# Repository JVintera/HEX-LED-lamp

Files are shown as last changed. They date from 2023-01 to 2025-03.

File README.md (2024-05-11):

# HEX-LED-lamp
<h1>LED lampička na tři způsoby</h1>
 
<h2>LED lampička</h2>
<p>Původní verze využívá LED modul ze žárovky. Následně vytvořena varianta se supersvítivými LED, aby bylo možné použít lampičku i jako dětskou promítačku.</p>
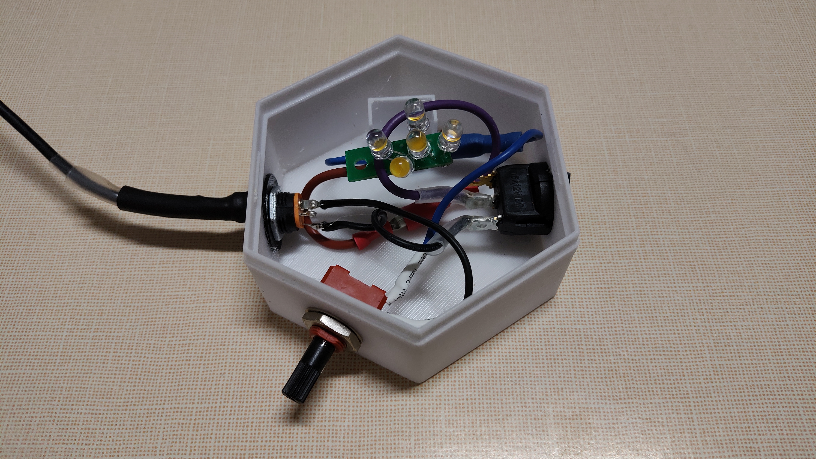
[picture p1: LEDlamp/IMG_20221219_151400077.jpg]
Lampička s LED modulem ze žárovky

LED lampička

<h3>Schéma zapojení</h3>
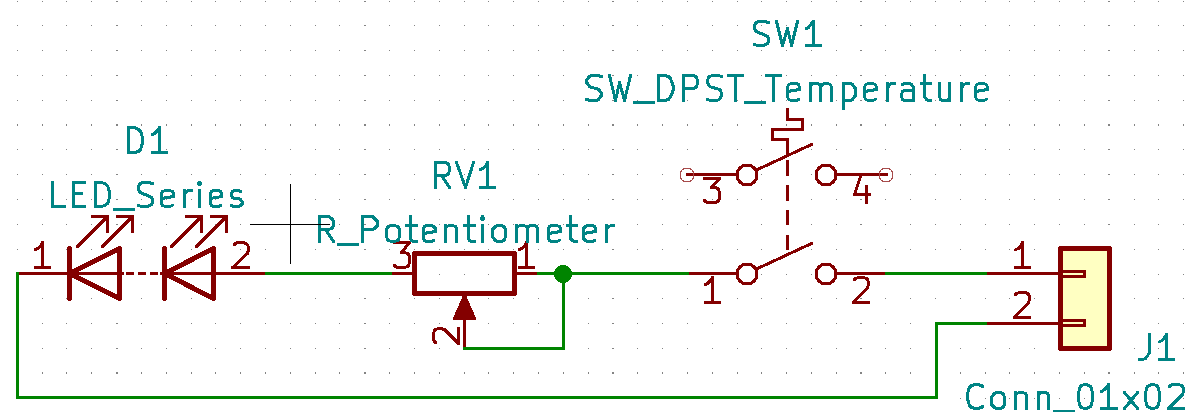
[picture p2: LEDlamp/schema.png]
Chema zapojeni


<h3>Soupis použitých komponent</h3>
<ul>
  <li>SW1 - spínač - <a href="https://ecom.cz/eshop/detail/56333-VP-R13-112B-BRBT2">VP-R13-112B BRBT2</a></li>
  <li>RV1 - trimr - <a href="https://ecom.cz/eshop/detail/48315-MCA14-NHC0-10K-KA">MCA14 NHC0 10K KA</a></li>
  <li>Hřídelka k trimru - <a href="https://ecom.cz/eshop/detail/3047-HRIDEL-CA-14073-1">HRIDEL CA-14073-1</a></li>
  <li>J1 - napájecí konektor - <a href="https://www.laskakit.cz/napajeci-konektor-dc-022-5-5-2-1mm-do-panelu/">Napájecí konektor DC-022 5,5/2,1mm - do panelu</a></li>
  <li>D1 - LED - podle potřeby: LED modul ze žárovky, nebo např. <a href="https://ecom.cz/eshop/detail/29727-LED-FYL-5014UWC1C">LED-FYL-5014UWC1C</a></li>
  <li>Zdroj - podle použitých LED, často je možné použít nabíječku na telefon</li>
</ul>

<h3>3D modely tištěných dílů a fotografie</h3>
<p>Model krabičky vychází z <a href="https://www.thingiverse.com/thing:2503641">Hexagonal LED Lamp with USB chargeable 18650 battery</a></p>
<p>3D modely pro tisk <a href="https://www.printables.com/cs/model/289219-hexagon-led-lamp">Hexagon LED lamp</a></p>

<h3>Problémy a řešení</h3>
<p>Robírání LED žárovek: Žárovka ve které odešel zdroj může mít skleněnou, nebo plastovou baňku. U skleněné lze nahřát lepidlo v místě spoje baňky a těla (přp. chladiče) žárovky. Lze fénem nebo horkovzdušnou pistolí. Předem počítejte s vysokými teplotami, takže např. kožené dílenské rukavice a místo, kam je možné odkládat horkou žárovku si připravte předem. Poté, co povolí lepidlo, baňku lze tahem pomalu odlepovat. Nejde to zcela zlehka, ale ani moc ztuha. Buďte též opatrní, abyste skleněnou baňku nerozmáčkly. Plastová baňka se při vyšších teplotách deformuje, ale lze ji snadno uříznout např. pilkou na železo, nebo prostě vypáčit šroubovákem a vylámat kleštěmi.</p>
<p>LED modul ze žárovky: Moduly jsou na různá napětí. Někdy lze odvodit napětí od typu a řazení LED. Pokud ale máte regulovatelný zdroj DC napětí a ampérmetr, nastavte nulové napětí, připojte žárovku a s ní do série ampérmetr. Pomalu zvyšujte napětí a sledujte (případně si i zapisujte) procházející proud. Ve chvíli, kdy bude LED svítit jasným světlem narazíte na oblast, kde se náhle při malém zvýšení napětí prudce zvýší proud. Provozní napětí bývá v oblasti tohoto zlomu (viz <a href="https://cs.wikipedia.org/wiki/LED">VA charakteristika LED, propustný směr</a>). Pokud chcete dlouhou životnost LED, snižte napětí těsně před tento zlom. Pokud chcete vyšší svítivost na úkor zkrácení životnosti, provozujte LED těsně za tímto zlomem.</p>
<p>Volba zdoje: Pokud použijete spínaný zdroj konstantního napětí se stítkovým napětím např. 5 V DC (běžné nabíječky), můžete se setkat s tím, že zdroj má na prázdno (bez zatížení) vírazně vyšší napětí. Abyste ochránili LED, stačí přidat do série tzv. <a href="https://cs.wikipedia.org/wiki/P%C5%99ed%C5%99adn%C3%ADk">předřadný rezistor</a>. Hodnotu lze <a href="https://youtu.be/mbZndNbmDEs">vypočítat</a>. Pokud použijete napětí na prázdno, LED budou svítit nepatrně menším jasem. Proto je možné zdroj zatížit, např. potenciometrem na kterém nastavíme takovou hodnotu, aby jím protékal zhruba stejný proud, jako požadujeme pro LED, a změříme na něm napětí. Lze samozřejmě postupovat i jinak. Např. můžete koupit <a href="https://youtu.be/iGyiqOaCaCM">zdroj proudu</a>.</p>
<p>Připevnění LED: Jelikož i LED vyzařují kromě viditelného spektra i infračervené (ohřívají se), přilepení LED modulu tavnou pistolí není použitelné. Po delším svícení se lepidlo rozehřálo. Ze stejného důvodu je i problematické přímé přišroubování k vytištěné plastové destičce (viz foto výše). Řešením jsou např. nízké distanční sloupky. Pokud jsou ale kovové, je třeba zajistit, aby na LED modulu nezkratovali vodivé cesty.</p>

<hr>
<!-- ********************************************************************* -->

<h2>WI-FI lampička</h2>
<p>Lampička ovládaná tlačítkem, nebo přes wi-fi. Opět použit LED modul ze žárovky. První verze od J. Lelek, viz
  <a href="WIFIlamp/v2/dokumentace.docx">dokumentace.docx</a></p>
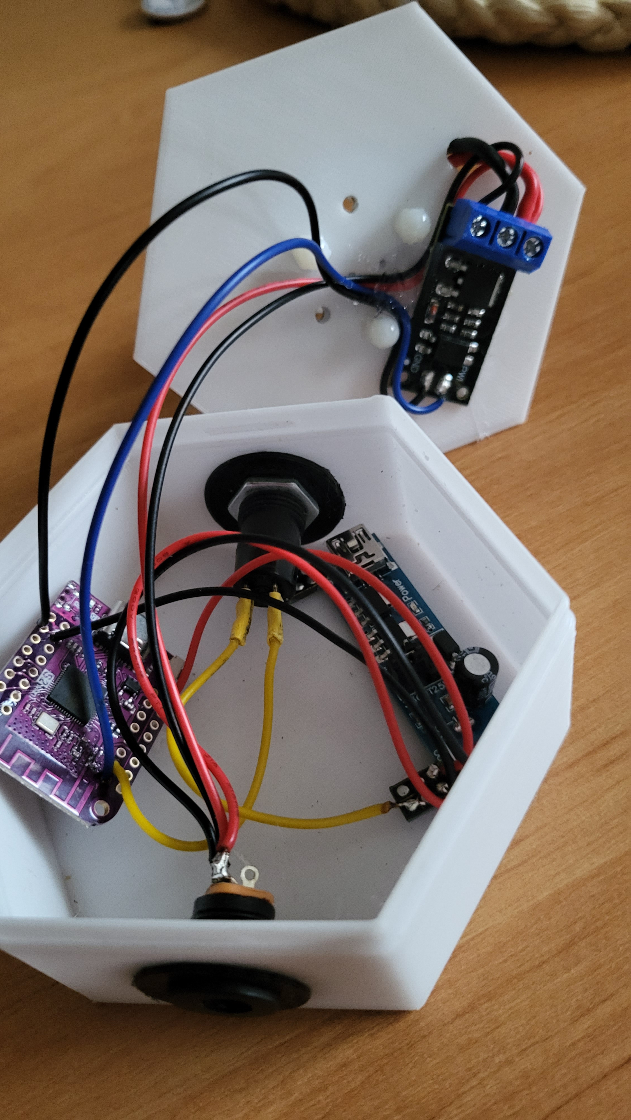
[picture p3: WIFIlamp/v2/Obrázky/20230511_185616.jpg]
WIFI lampička

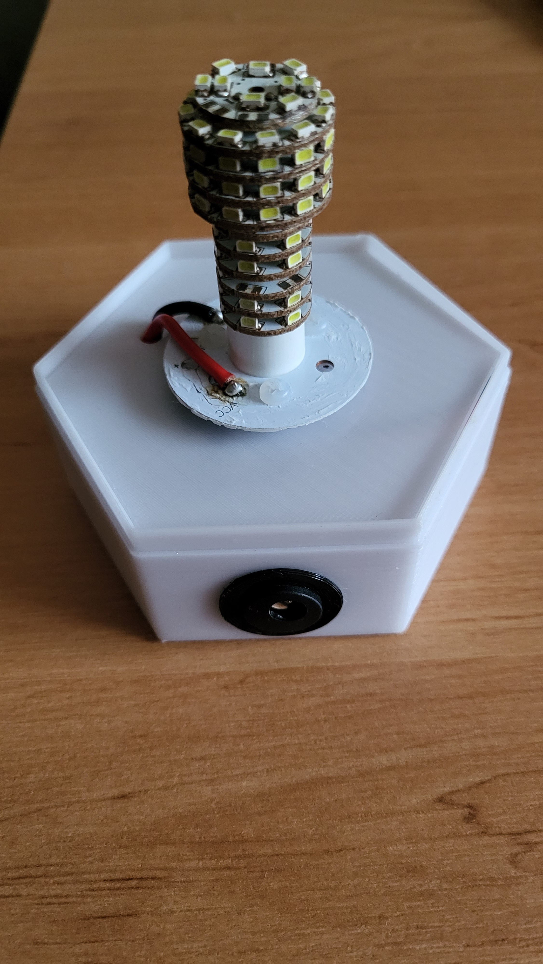
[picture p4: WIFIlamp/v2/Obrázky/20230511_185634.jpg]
WIFI lampička


<h3>Schéma zapojení</h3>
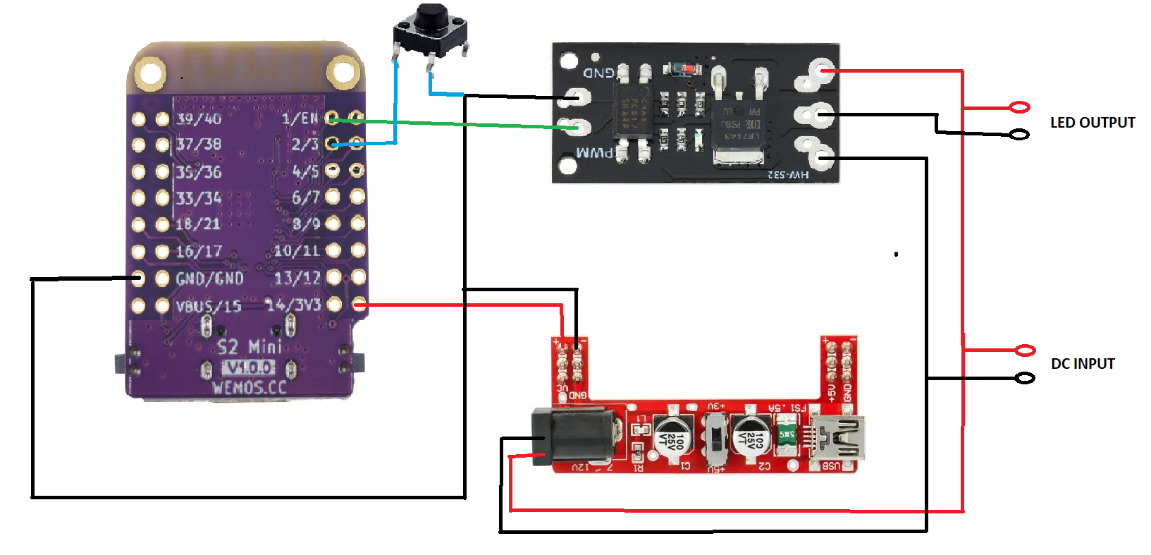
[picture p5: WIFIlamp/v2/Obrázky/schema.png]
Schema zapojeni


<h3>Programy a webová vizualizace</h3>
<p><a href="WIFIlamp/WIFIlamp_v3/WIFIlamp_v3.ino">WIFIlamp_v3.ino</a> - LED modul ze žárovky, přepínání tlačítkem a přes webovou stránku, která běží na ESP32.</p>
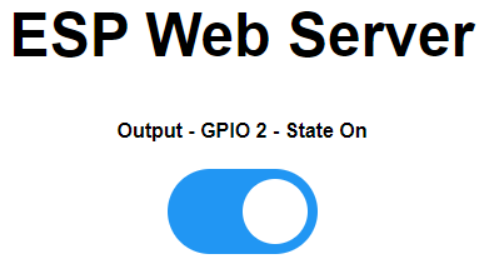
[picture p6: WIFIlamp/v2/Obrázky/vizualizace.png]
Vizualizace


<h3>Soupis použitých komponent</h3>
<ul>
  <li>ESP 32 S2 mini - <a href="https://pajenicko.cz/wemos-s2-mini-wifi-esp32-s2">Wemos S2 Mini Wifi ESP32-S2</a></li>
  <li>Stabilizátor napětí - <a href="https://dratek.cz/arduino/5002-napajeci-modul-nepajiveho-pole-mb102.html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">Napájecí modul nepájivého pole MB102</a></li>
  <li>Unipolární tranzistor pro spínání LED modulu - <a href="https://www.laskakit.cz/pwm-mosfet-modul-d4184--40vdc-50a/">PWM MOSFET modul D4184, 40VDC 50A</a></li>
  <li>Tlačítko pro ovládání lampičky</li>
  <li>LED modul z LED žárovky</li>
</ul>

<h3>3D modely tištěných dílů a fotografie</h3>
<p>Model krabičky vychází z <a href="https://www.thingiverse.com/thing:2503641">Hexagonal LED Lamp with USB chargeable 18650 battery</a></p>
<p>3D modely pro tisk <a href="https://www.printables.com/cs/model/289219-hexagon-led-lamp">Hexagon LED lamp</a></p>

<h3>Problémy a řešení</h3>
<p>...</p>

<h3>Co dál?</h3>
<p>...</p>

<h3>Literatura</h3>
<ul>
  <li><a href="https://randomnerdtutorials.com/esp32-esp8266-web-server-physical-button/">SP32/ESP8266: Control Outputs with Web Server and a Physical Button Simultaneously</a></li>
</ul>

<hr>
<!-- ********************************************************************* -->

<h2>RGB lampička</h2>
<p>Lampička s LED WS2812B ovládaná přes wi-fi. Tlačítkem přepínání přednastavených režimů. Přes wi-fi případně i další funkce. </p>
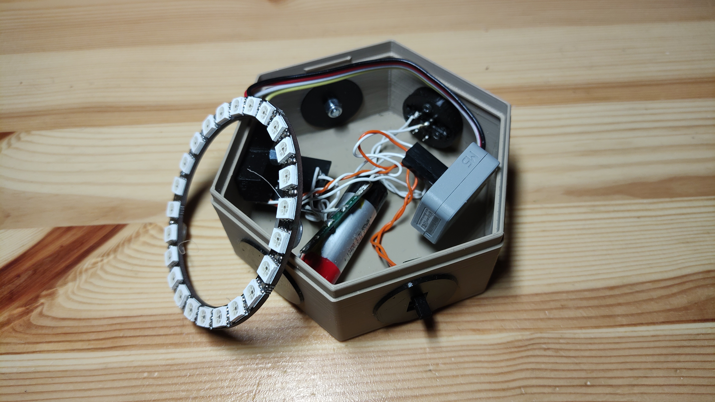
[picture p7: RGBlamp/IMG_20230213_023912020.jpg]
Vnitřek RGB lampičky


<h3>Schéma zapojení</h3>
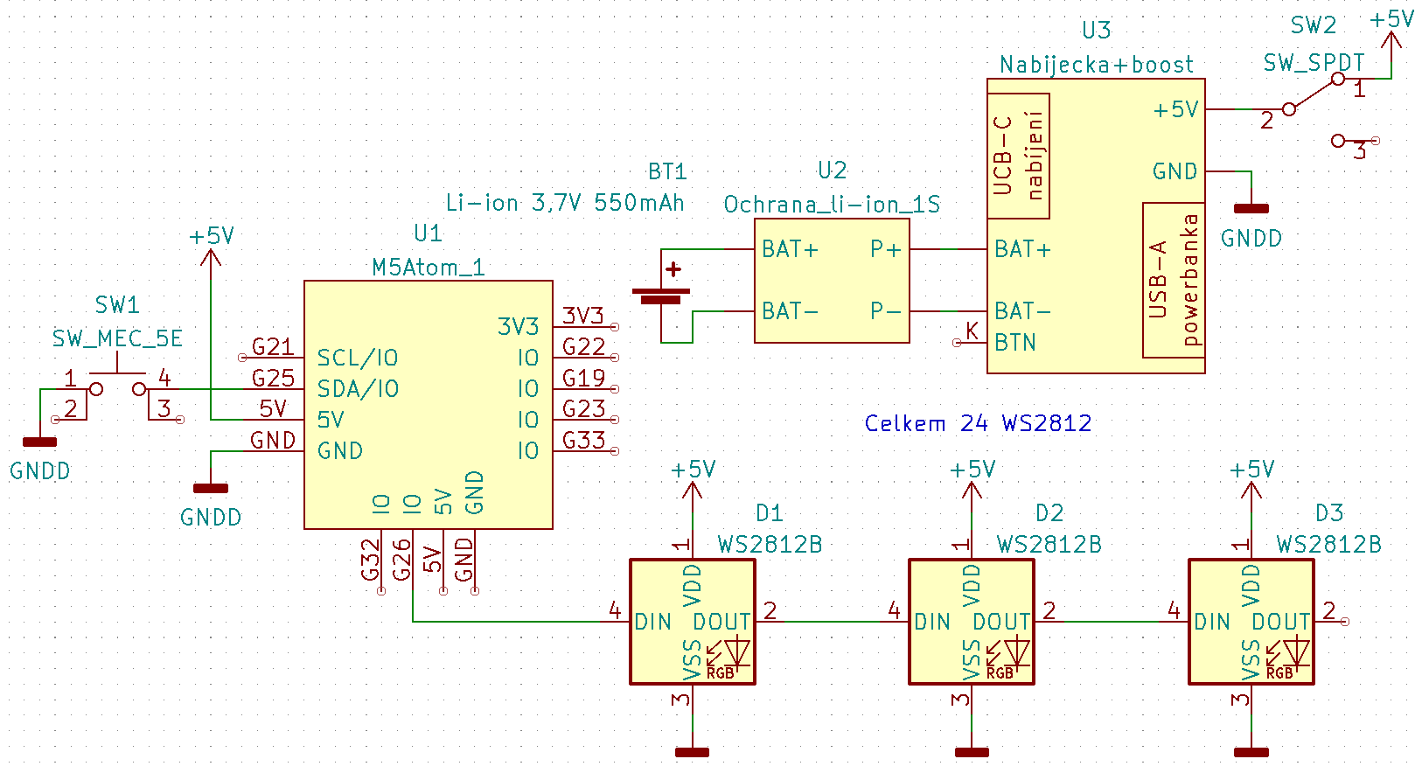
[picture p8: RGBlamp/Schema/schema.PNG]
Chema zapojeni


<h3>Programy a IoT cloud</h3>
<p><a href="RGBlamp/RGBlamp_v1/RGBlamp_v1.ino">RGBlamp_v1.ino</a> - zapnutí a vypnutí LED jedním tlačítkem (Tlačítko i LED na M5ATOM)</p>
<p><a href="RGBlamp/RGBlamp_v2/RGBlamp_v2.ino">RGBlamp_v2.ino</a> - stmívání LED jedním tlačítkem (Tlačítko i LED na M5ATOM)</p>
<p><a href="RGBlamp/RGBlamp_v3/RGBlamp_v3.ino">RGBlamp_v3.ino</a> - zapínání a vypínání externích LED WB2812B tlačítkem na pinu G25, použit efekt Rainbow</p>
<p style="color:red">POZOR! V programech nepoužívejte pravé SSID s heslem pro Wi-fi, případně další citlivé údaje.</p>
<p><a href="RGBlamp/RGBlamp_v4/RGBlamp_v4.ino">RGBlamp_v4.ino</a> - externí LED WB2812B přepínané tlačítkem a přes Blynk, použit efekt Rainbow</p>
<p><a href="RGBlamp/RGBlamp_v5/RGBlamp_v5.ino">RGBlamp_v5.ino</a> - externí LED WB2812B přepínané tlačítkem a přes Blynk, použit efekt Rainbow, pokud není wi-fi v dosahu, funguje ovládání tlačítkem</p>
<p>Šablona (template) v Blynk IoT:</p>
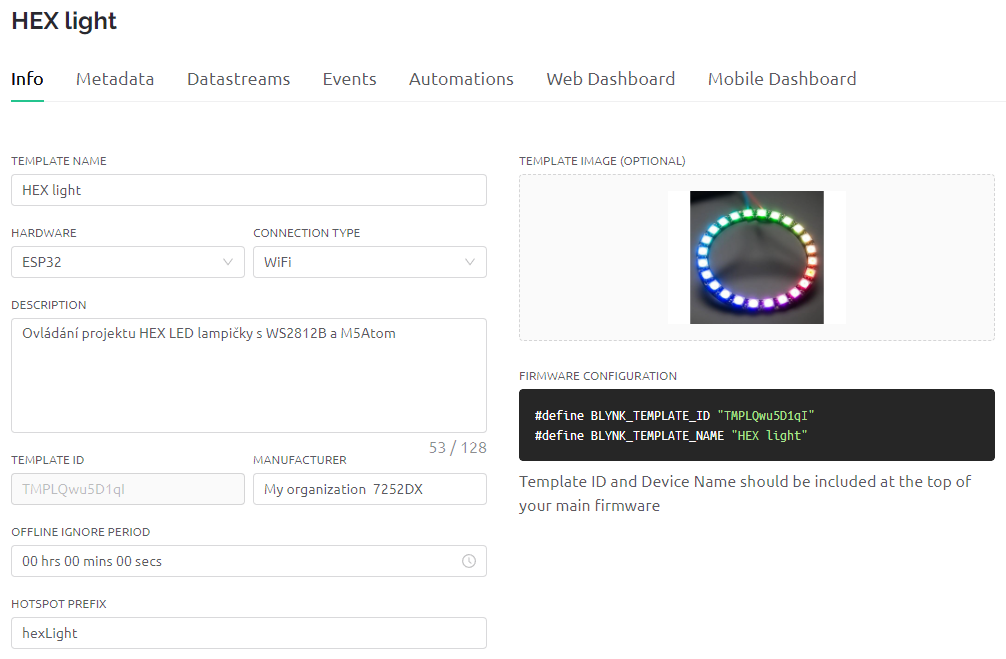
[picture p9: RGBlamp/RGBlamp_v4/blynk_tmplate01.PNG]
Blynk - template->info

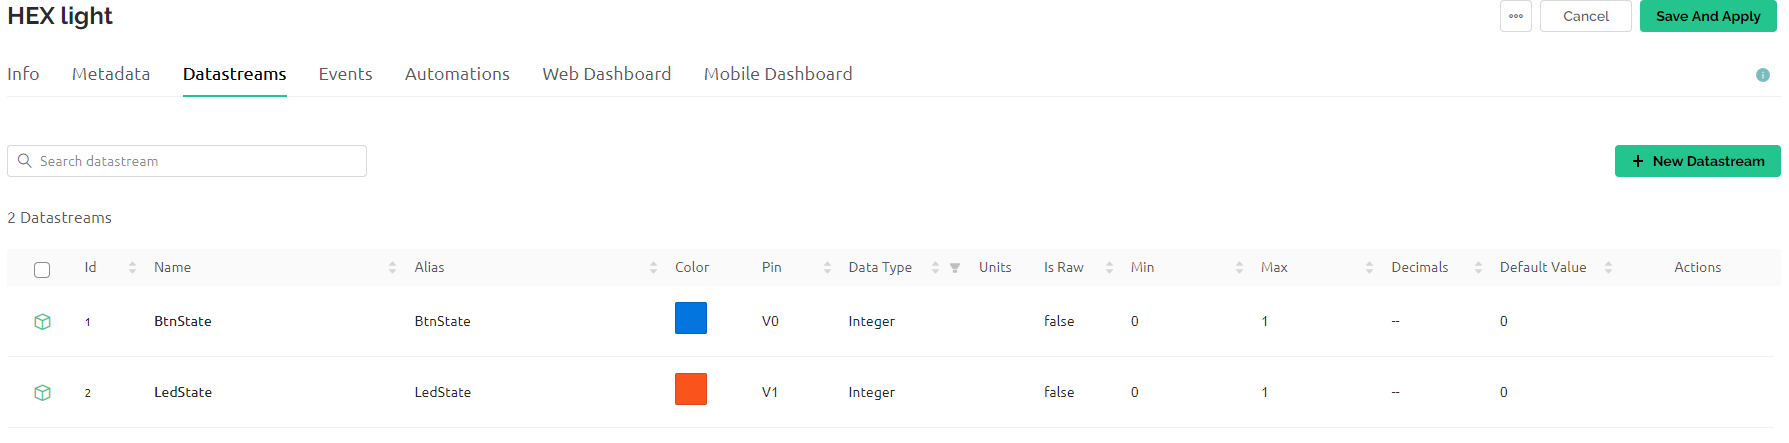
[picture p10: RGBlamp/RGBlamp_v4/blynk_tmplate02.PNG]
Blynk - template->datastreams

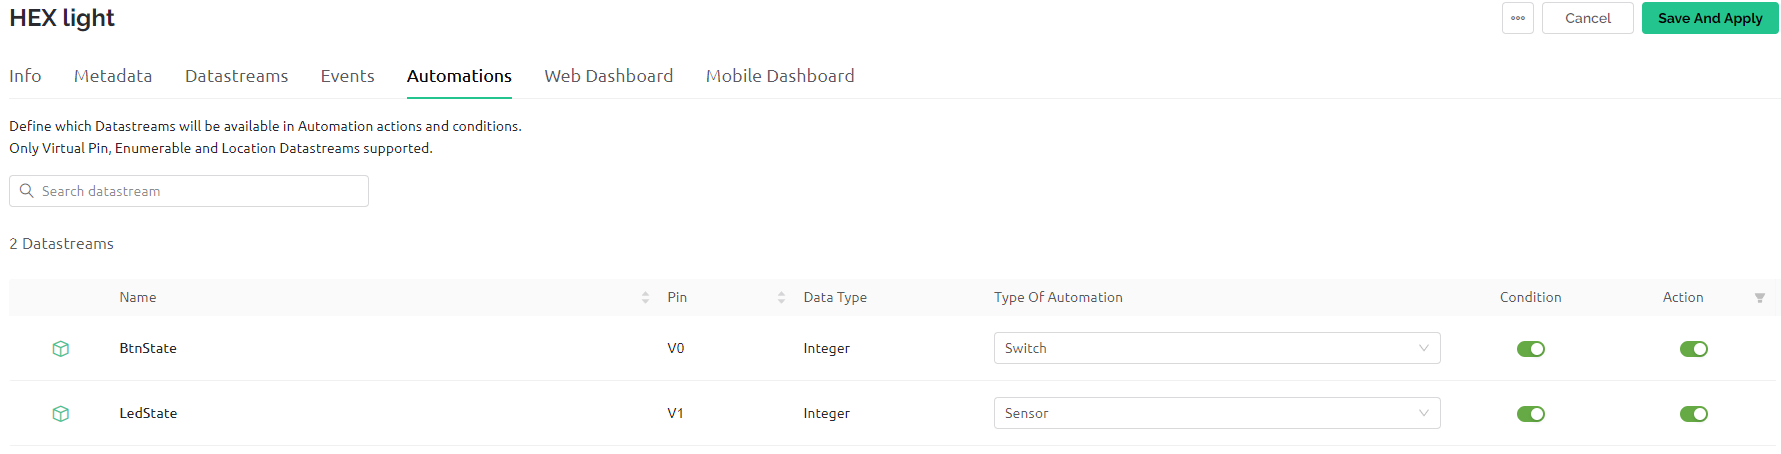
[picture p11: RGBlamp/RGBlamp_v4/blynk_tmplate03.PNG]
Blynk - template->automations

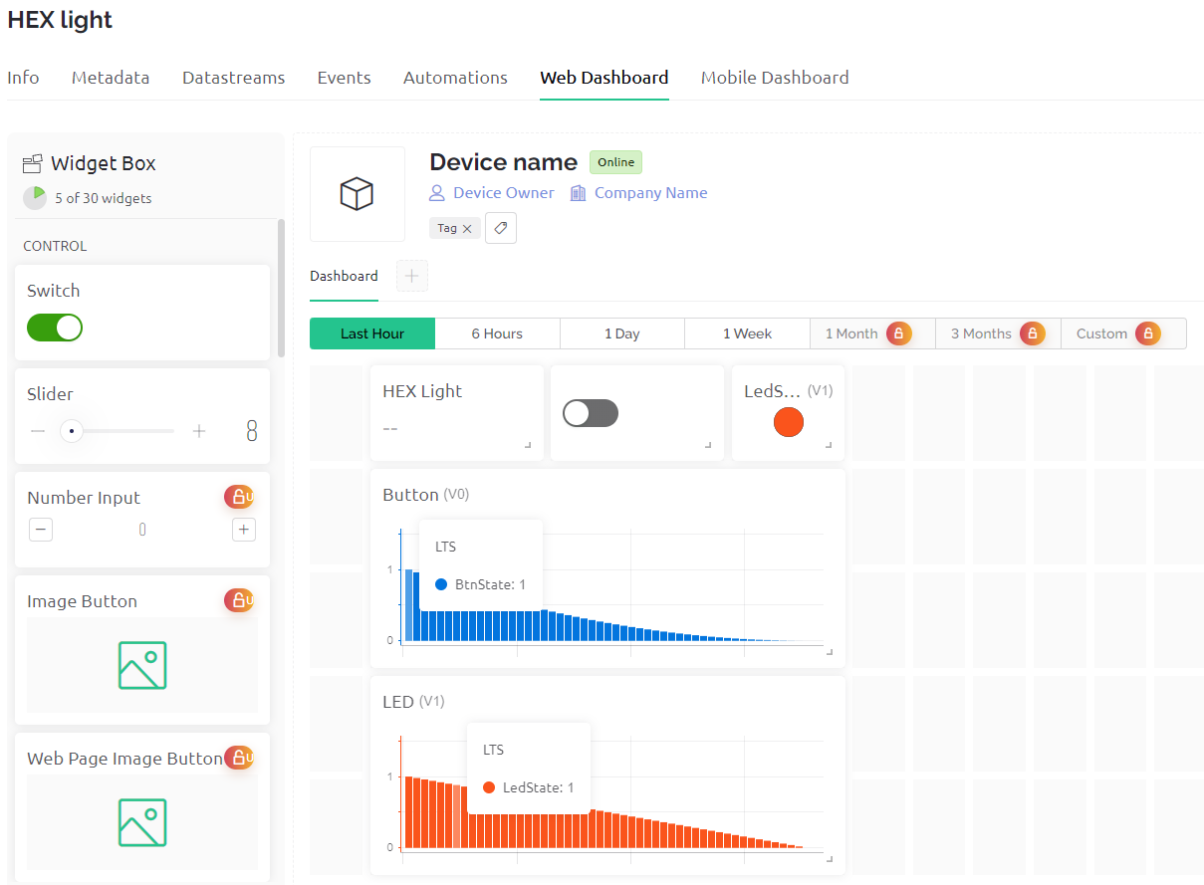
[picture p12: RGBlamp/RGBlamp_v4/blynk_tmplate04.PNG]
Blynk - template->web dashboard

<p>Z této šablony bylo vytvořeno zařízení (+ New device). V záložce Device info lze najít vygenerovaný TOKEN, který je nutné zkopírovat do programu.</p>
<p><a href="RGBlamp/RGBlamp_v6/RGBlamp_v6.ino">RGBlamp_v6.ino</a> - externí LED WB2812B přepínané tlačítkem a přes Arduino IoT cloud, režimy: rozsvícení barevného světla s nastavitelnou barvou, efekt Rainbow, blikající hvězdičky, policejní majáček a oranžový majáček</p>
<p>Návod na Arduino IoT cloud viz literatura. Konkrétní nastavení:</p>
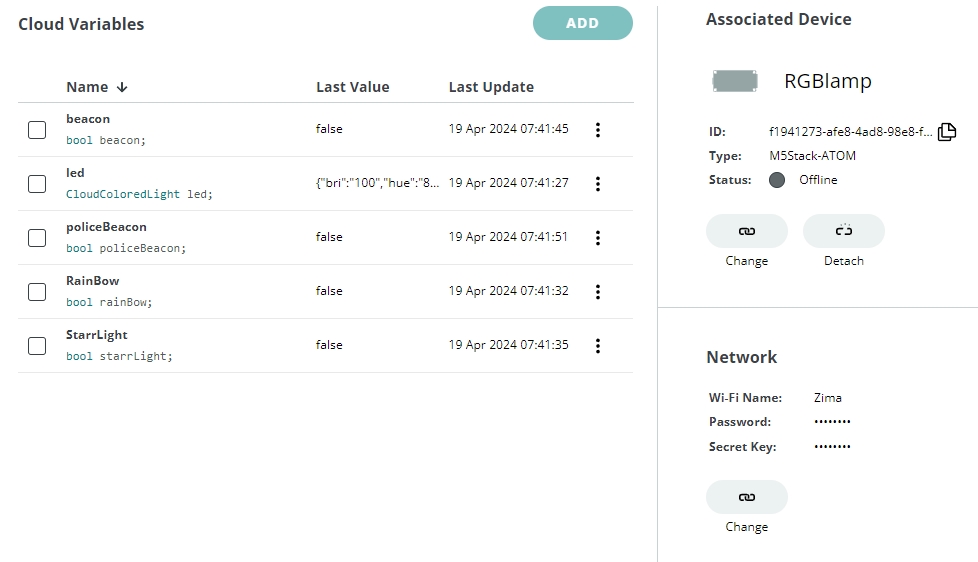
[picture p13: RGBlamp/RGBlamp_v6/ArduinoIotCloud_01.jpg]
Cloud variables

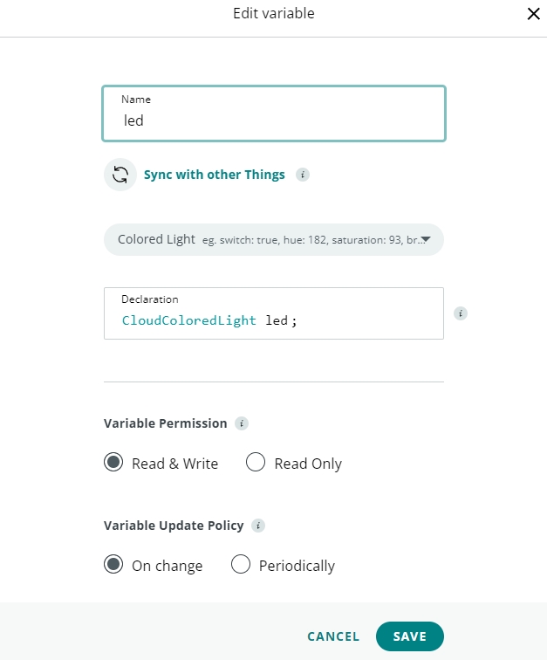
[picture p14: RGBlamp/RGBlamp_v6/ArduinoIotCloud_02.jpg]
Cloud variables - edit variable led

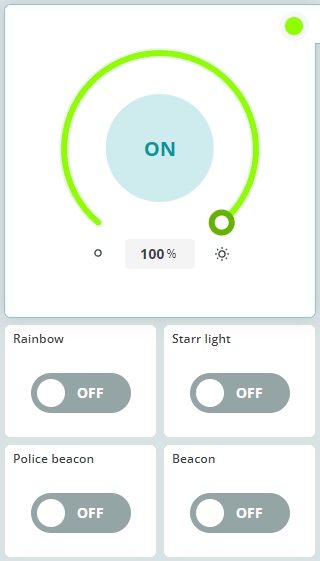
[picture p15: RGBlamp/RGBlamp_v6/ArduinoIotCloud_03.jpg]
Dashboard

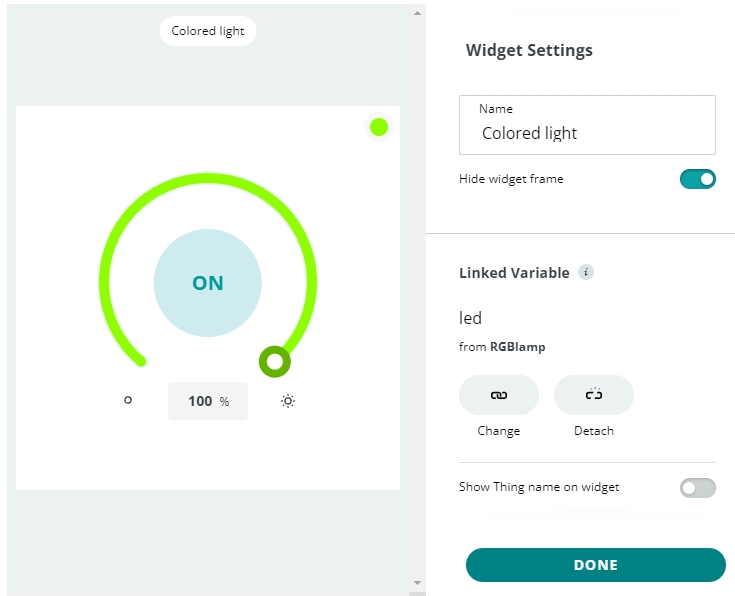
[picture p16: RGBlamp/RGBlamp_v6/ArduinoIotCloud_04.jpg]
Dashboard - edit colored light


<h3>Soupis použitých komponent</h3>
<ul>
  <li>U1 - řídící jednotka - <a href="https://rpishop.cz/kontrolery/2759-m5stack-atom-lite-esp32-vyvojovy-kit.html">M5Stack ATOM Lite ESP32</a></li>
  <li>D1 až D24 - RGB LED - <a href="https://www.laskakit.cz/24x-inteligentni-rgb-led-neopixel-kruh-65--ws2812b--5050--5v/">Kruh 24x RGB LED NeoPixel Ø65, WS2812B, 5050, 5V</a></li>
  <li>U2 - ochrana Li-ion baterie - <a href="https://www.laskakit.cz/ochrana-li-ion-baterie-1s-3a/">Ochrana li-ion baterie 1S 3A</a></li>
  <li>U3 - nabíjecí modul - <a href="https://www.laskakit.cz/nabijecka-boost-pro-usb-powerbank-5v--usb-c/">Nabíječka + boost pro USB Powerbank 5V, USB-C</a></li>
  <li>SW1 - tlačítko - <a href="https://ecom.cz/eshop/detail/68498-T-0660HAC-160G">Tlačítko spínací do PS,12V/50,výška 6mm</a></li>
  <li>SW2 - spínač - <a href="https://ecom.cz/eshop/detail/70765-VP-SS12F15G6">Spínač SS12F15G6-G</a></li>
  <li>BT1 - li-ion akumulátor - např. <a href="https://www.laskakit.cz/geb-lipol-baterie-801454-580mah-3-7v-jst-ph-2-0/">GeB LiPol Baterie 801454 580mAh 3.7V JST-PH 2.0</a></li>
  <li>Propojovací vodiče - z UTP kabelu</li>
  <li>Programovací kabel - programovací kabel USB-A na USB-C</li>
</ul>

<h3>3D modely tištěných dílů a fotografie</h3>
<p>Model krabičky vychází z <a href="https://www.thingiverse.com/thing:2503641">Hexagonal LED Lamp with USB chargeable 18650 battery</a></p>
<p>3D modely pro tisk <a href="https://www.printables.com/cs/model/289219-hexagon-led-lamp">Hexagon LED lamp</a></p>

<h3>Problémy a řešení</h3>
<p>Stav baterie: použitý modul pro nabíjení baterie má signalizaci stavu baterie pomocí čtyř LED, ty ale po smontování lampičky nejsou vidět. Proto byl v místě LED dodatečně vyvrtán otvor.</p>

<h3>Co dál?</h3>
<p>Doprogramovat další režimy svícení a přepínat mezi nimi v aplikaci Blynk IoT. Případně ještě přidat další tlačítko na přepínání těchto režimů.</p>

<h3>Literatura</h3>
<ul>
  <li><a href="https://docs.m5stack.com/en/core/atom_lite">M5Stack - ATOM Lite</a></li>
  <li><a href="https://blynk.io/">IoT cloud Blynk</a></li>
  <li><a href="https://youtu.be/IQyistaqj1U">Oficiální video tutoriál od Blynk</a></li>
  <li><a href="https://docs.blynk.io/en/getting-started/what-do-i-need-to-blynk">Dokumentace ke knihovně bklynk.h</a></li>
  <li><a href="https://randomnerdtutorials.com/esp32-useful-wi-fi-functions-arduino/">Článek připojení ESP32 pomocí Wi-fi</a></li>
  <li><a href="https://youtu.be/rcCxGcRwCVk?feature=shared">Návod na Arduino IoT cloud</a></li>
  <li><a href="https://docs.arduino.cc/arduino-cloud/guides/overview/">Dokumentace k Arduino IoT cloud</a></li>
  <li><a href="https://fastled.io/ /">Dokumentace ke knihovně FastLED pro RGB LED WS2812</a></li>
</ul>

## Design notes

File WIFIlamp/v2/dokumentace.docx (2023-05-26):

Lampička – druhá kompletní verze

Hardwarové složení

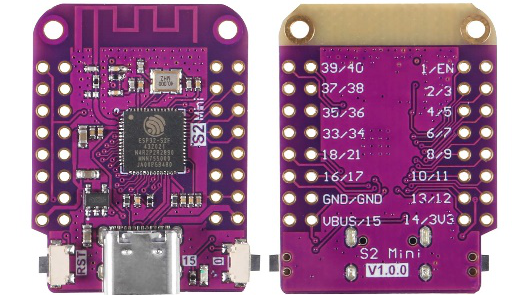
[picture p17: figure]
Amazon.com: ALAMSCN 2PCS Wemos/Lolin ESP32 S2 Mini WiFi IOT Board Based ESP32-S2FN4R2 4MB Flash 2MB PSRAM Type-C Connection Compatible with MicroPython : Electronics

- ESP 32 S2 mini

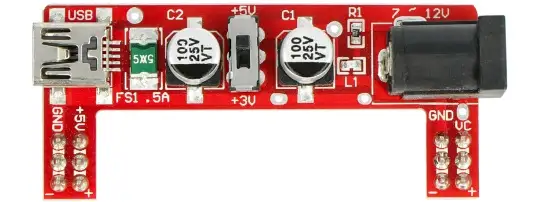
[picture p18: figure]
Obsah obrázku text, elektronika, Elektronické inženýrství, Obvodoví součástka Popis byl vytvořen automaticky

- stabilizátor napětí pro ESP

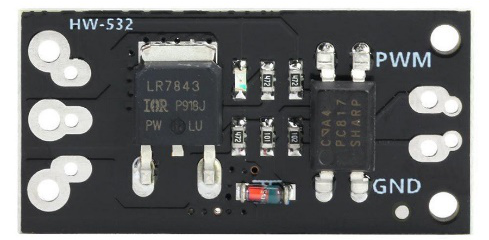
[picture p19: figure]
Obsah obrázku text, elektronika, snímek obrazovky, Elektronické inženýrství Popis byl vytvořen automaticky

- unipolární tranzistor pro ovládání LED modulu
- tlačítko fyzické ovládání lampičky
- LED modul z LED žárovky

Softwarové provedení

- použil jsem kód stažený z následující webové stránky, který jsem následně upravoval do současné podoby (změna připojení k síti, nastavení IP adresy, webové rozhraní atp…)
- https://randomnerdtutorials.com/esp32-esp8266-web-server-physical-button/

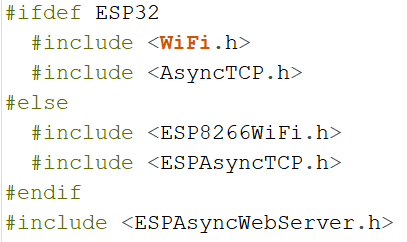
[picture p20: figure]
Obsah obrázku text, snímek obrazovky, Písmo Popis byl vytvořen automaticky

Na začátku kódu jsem zahrnuty knihovny pro fungování

- nejprve podmínka pro rozpoznání typu ESP, díky které se správně přiřazují knihovny pro ESP32 nebo ESP8266.
- první knihovna zajišťuje možnost připojení k síti WiFi a následnou virtuální komunikaci
- druhá knihovna slouží k rozpoznávání informací přicházejících ze zařízení připojených přes WiFi.
- třetí knihovna je pro oba druhy ESP stejná – jelikož je v lampičce použito fyzické tlačítko, zajišťuje neustálou synchronizaci serveru, tzn. že v případě zmáčknutí tlačítka dojde k okamžitému přepsání hodnoty na webu a zároveň zajišťuje přepisování hodnot, pokud je připojeno více zařízení.

Schema zapojení je totožné s následujícím obrázkem:


**schema je vlastní tvorba

Použití unipolárního tranzistoru uvnitř lampičky

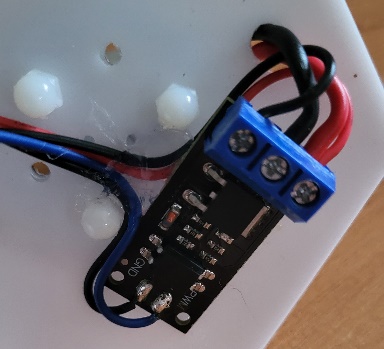
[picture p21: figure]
Obsah obrázku elektronika, Elektronické inženýrství, kabel, Elektronické zařízení Popis byl vytvořen automaticky
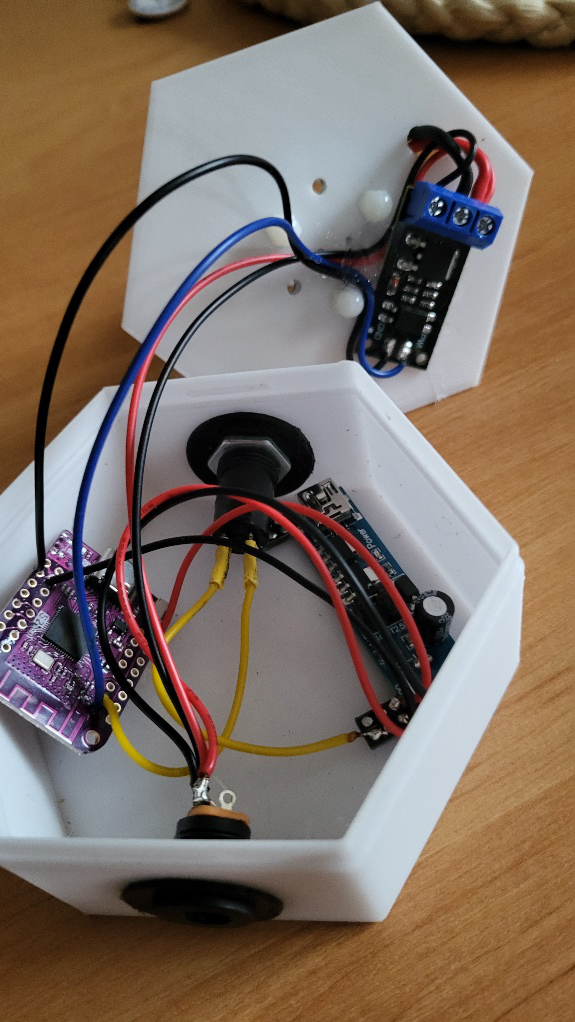
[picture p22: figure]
Obsah obrázku elektronika, kabel, Elektrické vedení, Elektronické inženýrství Popis byl vytvořen automaticky

- z přední strany na lampičce se nachází DC konektor, naproti němu se nachází tlačítko. Na levé straně je vidět ESP modul, na pravé straně již zmíněný stabilizátor.
- V průběhu realizace mě napadlo dodělat do lampičky také stmívání pro nastavování různé intenzity světla, nicméně se mi nepodařilo připojit to do stávajícího programu, takže z nápadu nakonec sešlo.
- Stmívání bylo realizováno pomocí PWM a mělo následující podobu:

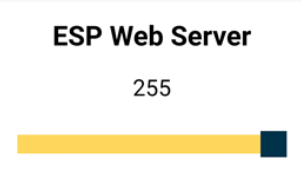
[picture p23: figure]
Obsah obrázku text, snímek obrazovky, Písmo, bílé Popis byl vytvořen automaticky

- místo ukázaného faderu je tedy v programu pouze tlačítko pro změnu stavu:

Obsah obrázku text, Písmo, snímek obrazovky, logo Popis byl vytvořen automaticky

Finální podoba lampičky:

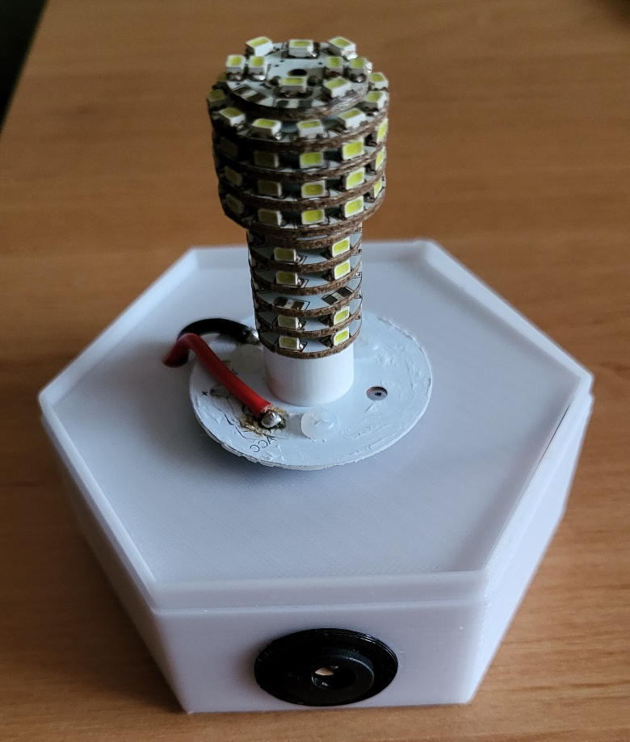
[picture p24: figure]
Obsah obrázku interiér, Železářské zboží pro domácnosti, nářadí, podlaha Popis byl vytvořen automaticky

Srovnání s předchozí verzí:

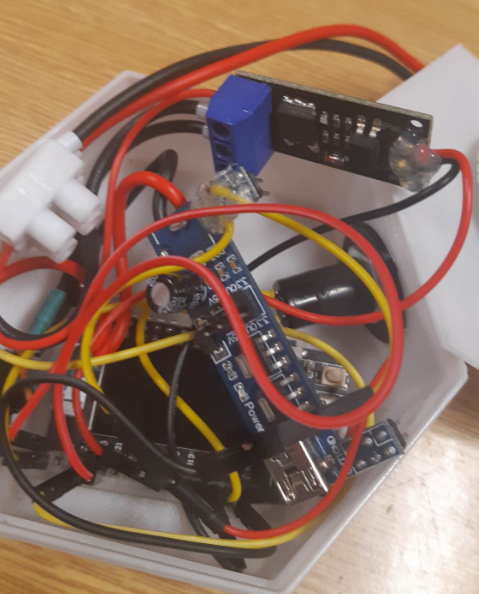
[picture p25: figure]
Obsah obrázku Elektrické vedení, kabel, elektronika, Elektronické inženýrství Popis byl vytvořen automaticky

Přechozí stav

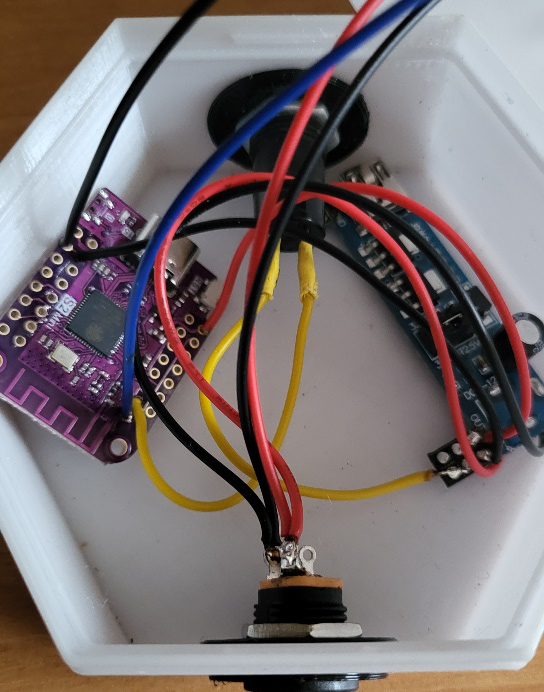
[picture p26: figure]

Současný stav

- jediný použitý zdroj je již v textu uveden
- obrázky byli kopírovány z obrázků google

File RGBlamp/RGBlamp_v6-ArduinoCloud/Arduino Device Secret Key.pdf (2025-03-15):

## RGBlamp

ESP32
M5Stack-ATOM | Configured on April 14, 2024

Device ID
f1941273-afe8-4ad8-98e8-fd96fc37f906

Secret Key
3@tGlYzqWA#vUQM1fHvkjPEib

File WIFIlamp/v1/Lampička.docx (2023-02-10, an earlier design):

Pololetní práce – 2.část

Lampička

V této práci budou popsány činnosti a principy zapojení, zprovoznění LED lampičky ovládané přes WEB SERVER a tlačítko.

Lampička může být spínána dvěma způsoby. První Způsob je spínání lampičky přes tlačítko (tlačítko je napojen na ESP32). Při zmáčknutí tlačítka bude lampička stále svítit, při opakovaném zmáčknutí zhasne.

Druhou variantou je spínání přes WIFI. V našem případě je to zprovozněno zase pomocí ESP32 (kód v příloze).

Obě tyto varianty jsou uskutečněny přes ESP 32. Následně ESP32 je napojeno na spínač spínaný pomocí unipolárního tranzistoru, který slouží ke spínání samotné lampičky. Tento Tranzistor je náhradou za relátko.

Použité součásti

-ESP32 WROOM:

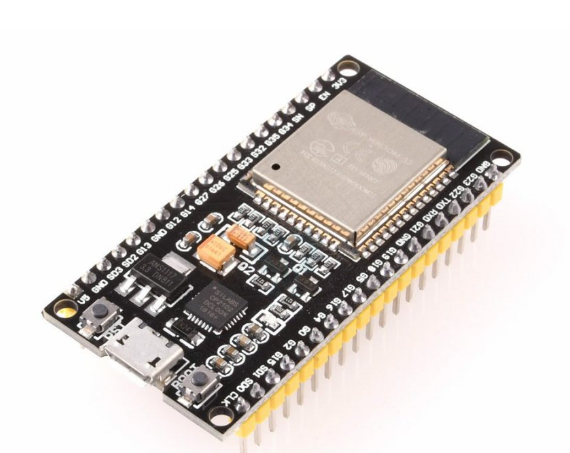
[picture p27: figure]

-tlačítko:

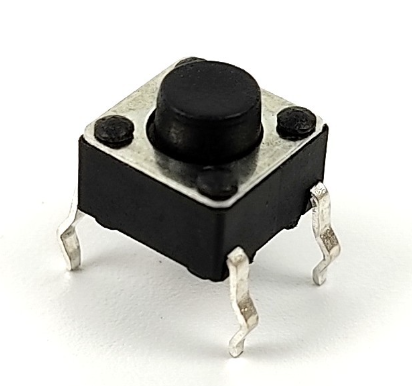
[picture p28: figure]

# -spínač spínaný tranzistorem Spínač MOSFET PWM, D4184:

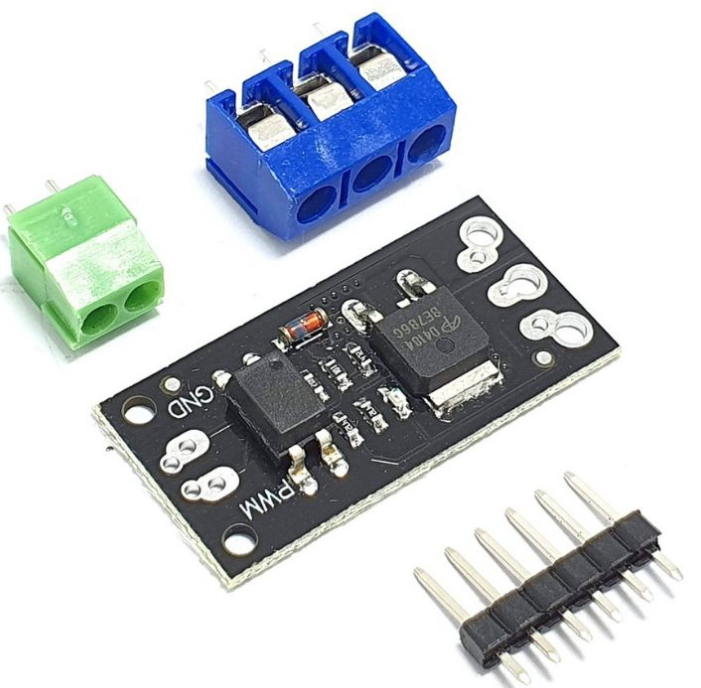
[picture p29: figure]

-další: propojovací drátky

: plastový kryt lampičky

: samotné LEDKY

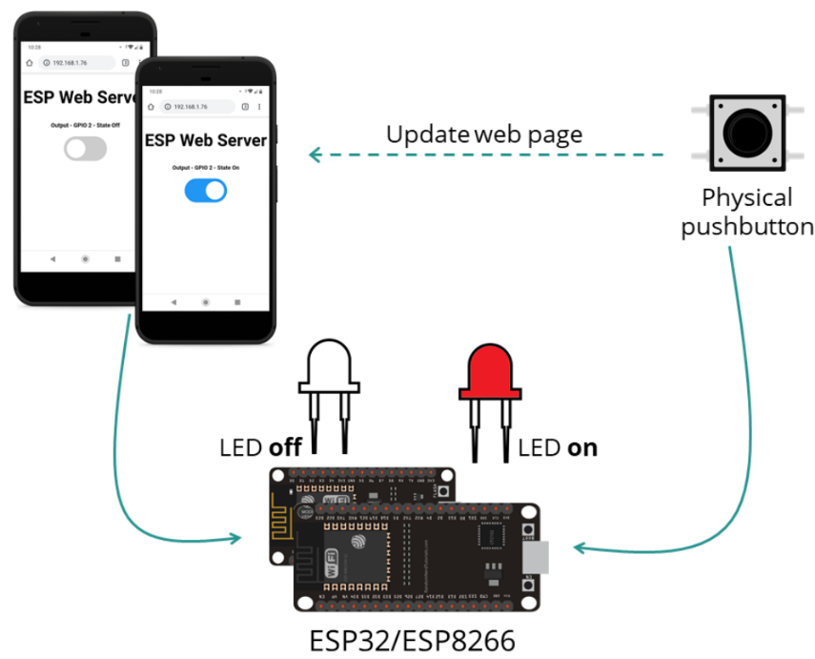
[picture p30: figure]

Schémata zapojení

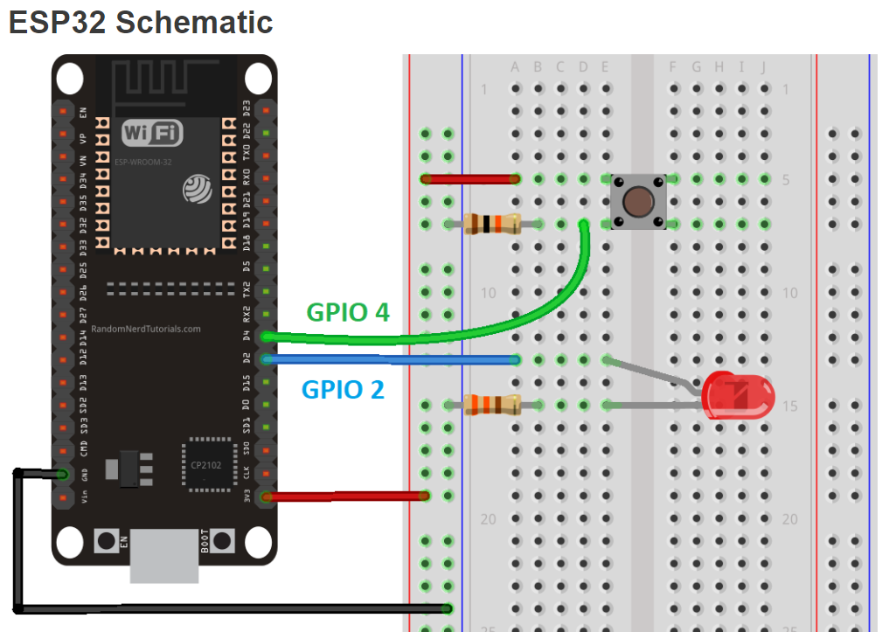
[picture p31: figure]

-mezi LED diodou a ESP32 je ještě spínací prvek

Fotky

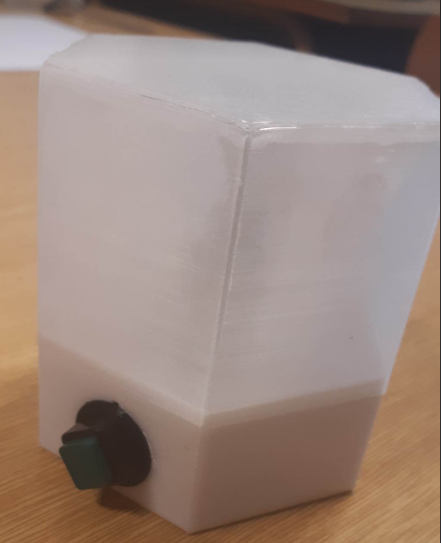
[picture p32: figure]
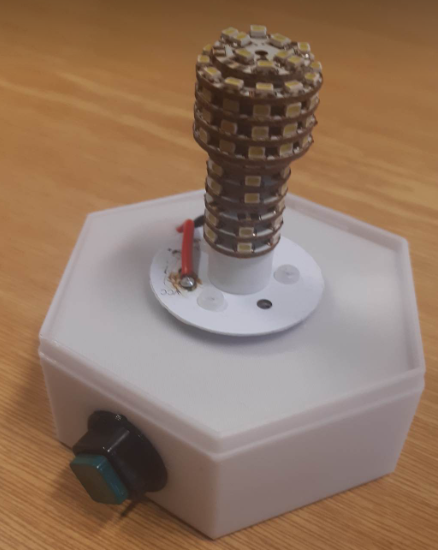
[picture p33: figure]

Zdroje

https://randomnerdtutorials.com/esp32-esp8266-web-server-physical-button/

https://dratek.cz/arduino/123949-spinac-mosfet-pwm-d4184.html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

-lampička byla sestavena Honzou Lelkem

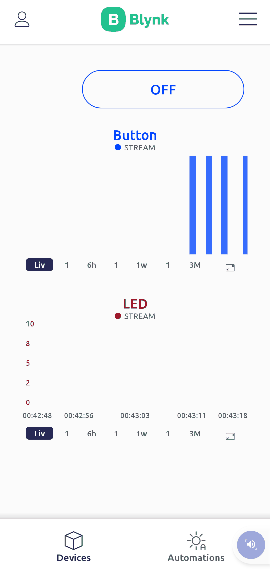
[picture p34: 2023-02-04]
pracovni/gif-20221026-004330.gif

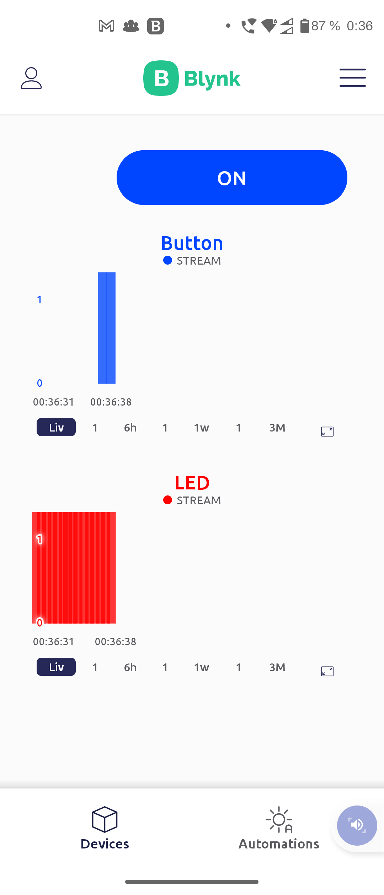
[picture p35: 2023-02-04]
pracovni/Screenshot_20221026-003639.png

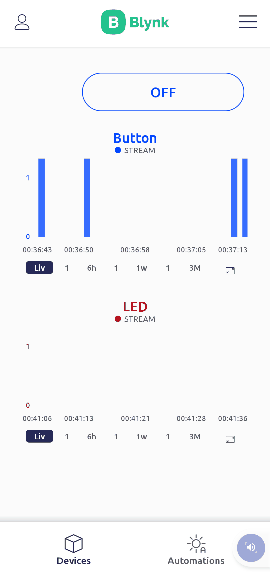
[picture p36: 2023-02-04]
pracovni/gif-20221026-004149.gif

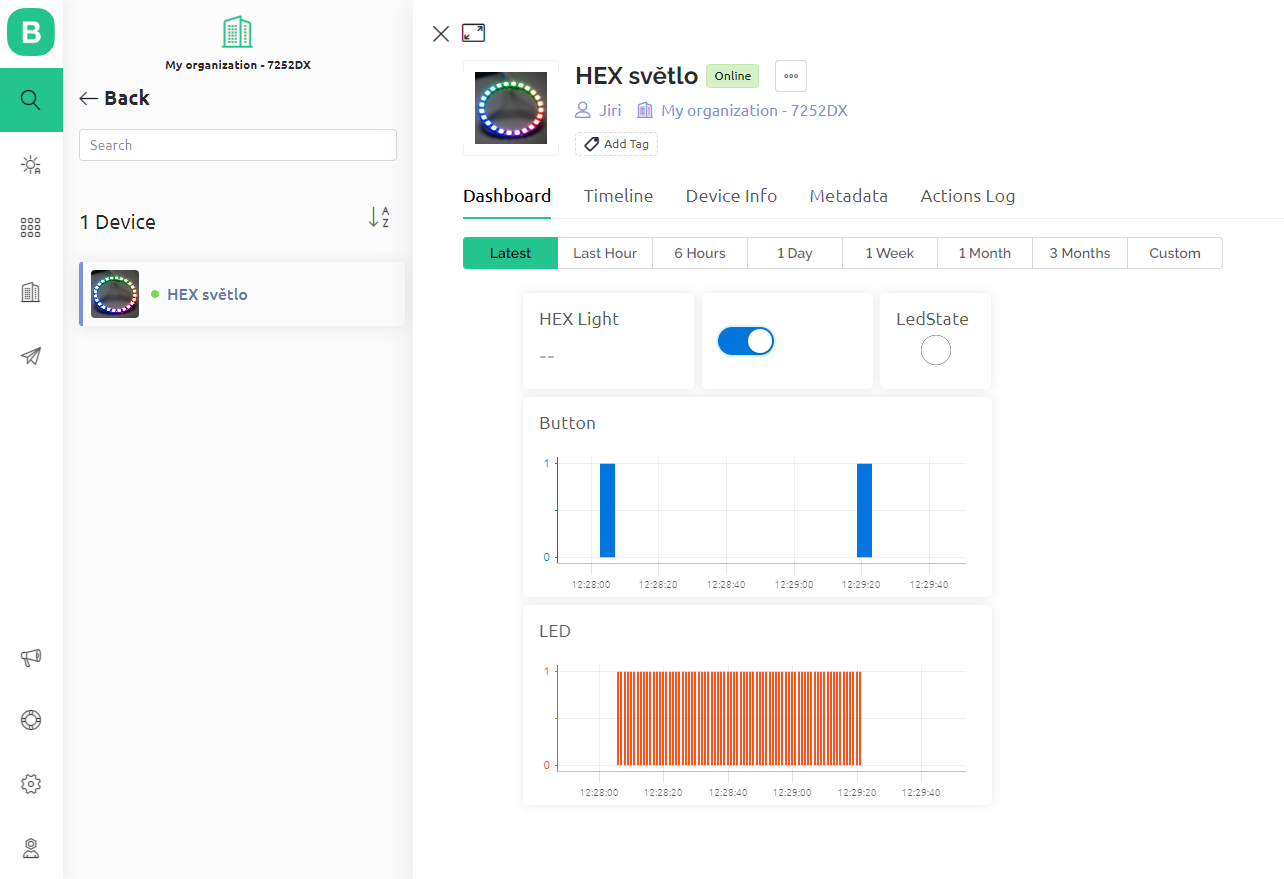
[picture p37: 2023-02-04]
pracovni/Bylnk web 2.PNG

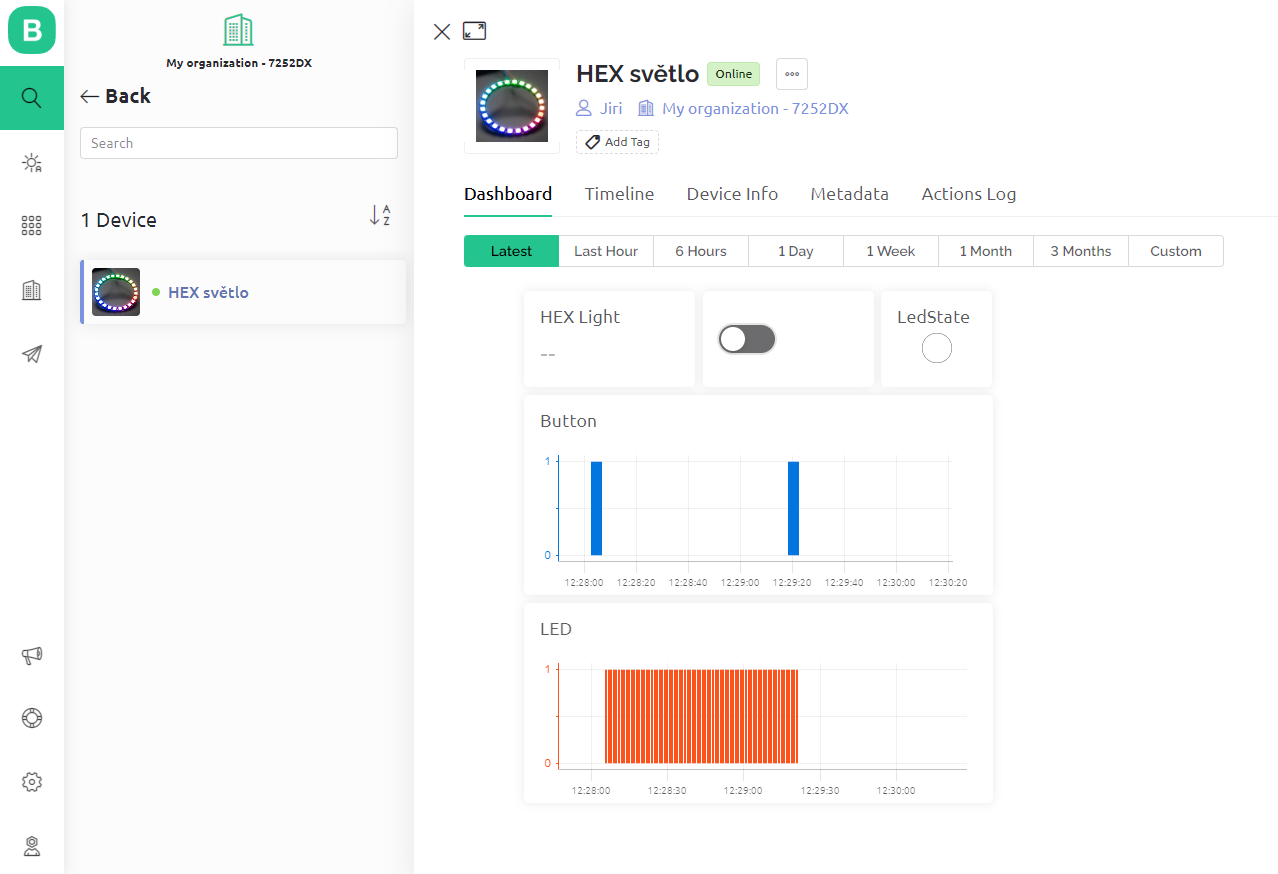
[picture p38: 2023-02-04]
pracovni/Blynk web 3.PNG

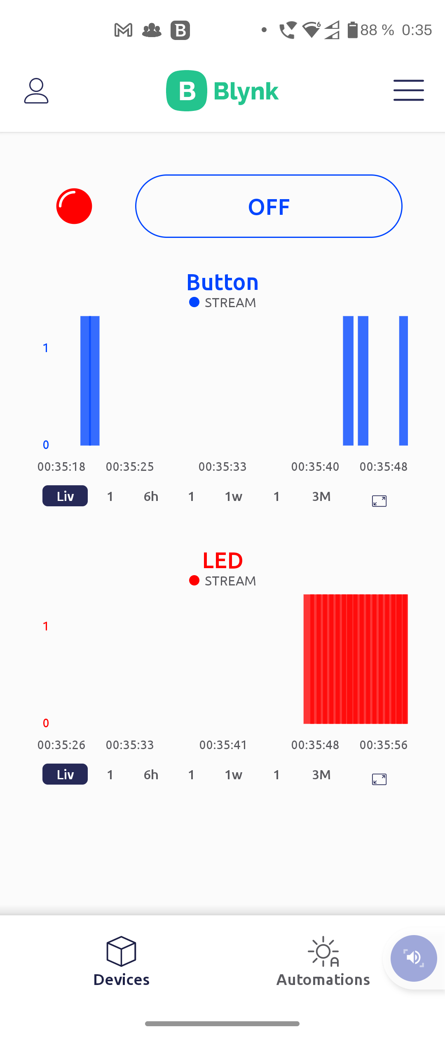
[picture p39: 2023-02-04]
pracovni/Screenshot_20221026-003556.png

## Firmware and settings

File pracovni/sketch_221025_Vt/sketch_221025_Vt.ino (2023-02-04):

//***************************************************
//Externí LED WB2812B přepínané tlačítkem a přes Blynk
//Efekt Rainbow
//***************************************************
/*Zajímavé odkazy
  Původní program
  je příklad z https://docs.m5stack.com/en/unit/neopixel
  resp. https://github.com/m5stack/M5Stack/blob/master/examples/Unit/RGB_LED_SK6812/display_rainbow/display_rainbow.ino
  Knihovna a obecné informace
  https://docs.m5stack.com/en/unit/neopixel
  https://github.com/FastLED/FastLED/wiki/Overview
  https://github.com/FastLED/FastLED/wiki/Pixel-reference#chsv
  https://cs.wikipedia.org/wiki/HSV
  Příklady
  https://wokwi.com/arduino/libraries/FastLED/Blink
  BLYNK IoT
  https://docs.blynk.io/en/getting-started/what-do-i-need-to-blynk
  Příklad pro tlačítko https://examples.blynk.cc/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
  Příklad pro LED https://examples.blynk.cc/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
*/
#include "M5Atom.h"
#include "FastLED.h"
#include <WiFi.h>
#include <WiFiClient.h>
#include <BlynkSimpleEsp32.h>

//Údaje Blynk
// Template ID, Device Name and Auth Token are provided by the Blynk.Cloud
// See the Device Info tab, or Template settings
#define BLYNK_TEMPLATE_ID "TMPLQwu5D1qI"
#define BLYNK_DEVICE_NAME "HEX light"
#define BLYNK_AUTH_TOKEN "n2AK1jAdi-jdgCZ0U4V1FFFHo2ysTxrg"
// Comment this out to disable prints and save space
#define BLYNK_PRINT Serial
char auth[] = BLYNK_AUTH_TOKEN;
// Your WiFi credentials.
// Set password to "" for open networks.
//char ssid[] = "Zima";
//char pass[] = "Ro2uJjej";
//char ssid[] = "Zima24_guest";
//char pass[] = "Zimikovi812/";
char ssid[] = "SPSELIT-host";
char pass[] = "SPSg21esT";
BlynkTimer timer; // Creating a timer object


//LED pasek/modul WS2812B
#define Neopixel_PIN 26
#define NUM_LEDS 24
CRGB leds[NUM_LEDS];
uint8_t gHue = 0;
int LED_brightness = 100;

//Integrovaná LED v M5Atom
#define Neopixel_PIN2 27
#define NUM_LEDS2 1
CRGB leds2[NUM_LEDS2];

//Tlačítko
#define BTN_PIN 25
bool stateB = 1; //Pomocná proměnná pro přepínání stavu LED
int BTN_last = 0; //Proměnná pro uložení předešlého stavu tlačítka
int BTN_cur = 0; //Proměnná pro uložení současného stavu tlačítka
int BTN_SW_last = 0; //Proměnná v Blynku pro uložení předešlého stavu tlačítka
int BTN_SW_cur = 0; //Proměnná v Blynku pro uložení současného stavu tlačítka


void setup() {
  M5.begin();
  Serial.begin(115200);

  pinMode(BTN_PIN, INPUT_PULLUP); //Nastavení tlačítka - vnitřní Pull-up rezistor
  // Neopixel initialization
  FastLED.addLeds<WS2812B, Neopixel_PIN2, GRB>(leds2, NUM_LEDS2).setCorrection(TypicalLEDStrip);
  FastLED.addLeds<WS2812B, Neopixel_PIN, GRB>(leds, NUM_LEDS).setCorrection(TypicalLEDStrip);
  FastLED.setBrightness(LED_brightness);
  //Na začátku se LED zhasnou
  fill_solid(leds, NUM_LEDS, CRGB(0, 0, 0)); //LED pásek zhasne
  fill_solid(leds2, NUM_LEDS2, CRGB(0, 0, 255)); //LED se rozsvítí modře a měla by po 50 ms změnit barvu
  FastLED.show();


  //Blynk.begin(auth, ssid, pass);
  // You can also specify server:
  Blynk.begin(auth, ssid, pass, "blynk.cloud", 80);
  //Blynk.begin(auth, ssid, pass, IPAddress(192,168,1,100), 8080);
  timer.setInterval(500L, myTimerEvent); //Staring a timer
  delay(50);
}

void myTimerEvent() // This loop defines what happens when timer is triggered
{
  Blynk.virtualWrite(V1, stateB);
  Serial.print("Hodnota posuvníku V1 je: ");
  Serial.println(stateB);
}

// Tato funkce bude volána při každém posuvníku Widget
// v aplikaci Blynk zapíše hodnoty do virtuálního pinu 0
BLYNK_WRITE(V0)
{
  int pinValue = param.asInt(); // přiřazení příchozí hodnoty z pinu V1 do proměnné
  BTN_SW_cur = pinValue;
  // Můžete také použít:
  // Řetězec i = param.asStr();
  // double d = param.asDouble();
  Serial.print("Hodnota posuvníku V0 je: ");
  Serial.println(pinValue);
}


void loop() {
  BTN_cur = digitalRead(BTN_PIN); //Čtení stavu tlačítka

  Blynk.run();
  timer.run(); // runs the timer in the loop

  //Pokud došlo k uvolnění hw tlačítka (was released),
  //nebo k uvolnění sw tlačítka, změní se stateB
  if (BTN_cur && !BTN_last || BTN_SW_cur && !BTN_SW_last) {
    stateB = !stateB;
  }
  if (stateB) {
    //Funkce je popsána v https://fastled.io/docs/3.1/group___colorutils.html
    fill_rainbow(leds, NUM_LEDS, gHue, 7);  // rainbow effect
    fill_solid(leds2, NUM_LEDS2, CRGB(0, 255, 0));
    FastLED.show();  // must be executed for neopixel becoming effective
    EVERY_N_MILLISECONDS(20) {
      gHue++;
    }
  }
  else {
    //Funkce je popsána v https://fastled.io/docs/3.1/group___colorutils.html
    fill_solid(leds, NUM_LEDS, CRGB(0, 0, 0));
    fill_solid(leds2, NUM_LEDS2, CRGB(255, 0, 0));
    FastLED.show();
  }
  BTN_last = BTN_cur;
  BTN_SW_last = BTN_SW_cur;
  M5.update();
}



//***************************************************
//Externí LED WB2812B přepínané tlačítkem
//Efekt Rainbow
//***************************************************
///*Zajímavé odkazy
//  Původní program
//  je příklad z https://docs.m5stack.com/en/unit/neopixel
//  resp. https://github.com/m5stack/M5Stack/blob/master/examples/Unit/RGB_LED_SK6812/display_rainbow/display_rainbow.ino
//  Knihovna a obecné informace
//  https://docs.m5stack.com/en/unit/neopixel
//  https://github.com/FastLED/FastLED/wiki/Overview
//  https://github.com/FastLED/FastLED/wiki/Pixel-reference#chsv
//  https://cs.wikipedia.org/wiki/HSV
//  Příklady
//  https://wokwi.com/arduino/libraries/FastLED/Blink
//*/
//#include "M5Atom.h"
//#include "FastLED.h"
//
////LED pasek/modul WS2812B
//#define Neopixel_PIN 26
//#define NUM_LEDS 24
//CRGB leds[NUM_LEDS];
//uint8_t gHue = 0;
//int LED_brightness = 20;
//
////Integrovaná LED v M5Atom
//#define Neopixel_PIN2 27
//#define NUM_LEDS2 1
//CRGB leds2[NUM_LEDS2];
//int LED_brightness2 = 5;
//
////Tlačítko
//#define BTN_PIN 25
//int BTN_last = 0; //Proměnná ro uložení předešlého stavu tlačítka
//int BTN_cur = 0; //Proměnná ro uložení současného stavu tlačítka
//
//void setup() {
//  M5.begin();
//  pinMode(BTN_PIN, INPUT_PULLUP); //Nastavení tlačítka - vnitřní Pull-up rezistor
//  // Neopixel initialization
//  FastLED.addLeds<WS2812B, Neopixel_PIN, GRB>(leds, NUM_LEDS).setCorrection(TypicalLEDStrip);
//  FastLED.setBrightness(LED_brightness);
//  FastLED.addLeds<WS2812B, Neopixel_PIN2, GRB>(leds2, NUM_LEDS2).setCorrection(TypicalLEDStrip);
//  FastLED.setBrightness(LED_brightness2);
//  //Na začátku se LED zhasnou
//  fill_solid(leds, NUM_LEDS, CRGB(0, 0, 0)); //LED pásek zhasne
//  fill_solid(leds2, NUM_LEDS2, CRGB(0, 0, 255)); //LED se rozsvítí modře a měla by po 50 ms změnit barvu
//  FastLED.show();
//  delay(50);
//}
//
//void loop() {
//  static bool stateB = 1; //Pomocná proměnná pro přepínání stavu LED
//  BTN_cur = digitalRead(BTN_PIN); //Čtení stavu tlačítka
//
//  //Pokud došlo k uvolnění tlačítka (was released)
//  if (BTN_cur && !BTN_last) {
//    stateB = !stateB;
//  }
//  if (stateB) {
//    //Funkce je popsána v https://fastled.io/docs/3.1/group___colorutils.html
//    fill_rainbow(leds, NUM_LEDS, gHue, 7);  // rainbow effect
//    fill_solid(leds2, NUM_LEDS2, CRGB(0, 255, 0));
//    FastLED.show();  // must be executed for neopixel becoming effective
//    EVERY_N_MILLISECONDS(20) {
//      gHue++;
//    }
//  }
//  else {
//    //Funkce je popsána v https://fastled.io/docs/3.1/group___colorutils.html
//    fill_solid(leds, NUM_LEDS, CRGB(0, 0, 0));
//    fill_solid(leds2, NUM_LEDS2, CRGB(255, 0, 0));
//    FastLED.show();
//  }
//  BTN_last = BTN_cur;
//  M5.update();
//}


//***************************************************
//Stmívání LED jedním tlačítkem
//***************************************************
/*Funkce pro práci s LED a tlačítkem jsou popsány v
  https://docs.m5stack.com/en/api/atom/system
  https://docs.m5stack.com/en/api/atom/button
  https://docs.m5stack.com/en/api/atom/led_display
*/
//#include "M5Atom.h"
//
//#define RGB_LED 0
//
//void setup() {
//  M5.begin(true, false, true);
//  Serial.begin(9600);
//  delay(50);
//  //Probliknutí LED (zeleně) jako signalizace, že LED funguje
//  M5.dis.setBrightness(255);
//  M5.dis.drawpix(RGB_LED, 0x00FF00);
//  delay(50);
//  M5.dis.drawpix(RGB_LED, 0x000000);
//}
//
//void loop() {
//  static uint8_t brightLED = 0;
//  static uint8_t brightB = 0;
//  static bool stateB = 0;
//  static byte modeB = 0;
////Proměnné help (mohou se jmenovat jakkoliv jinak) složí pro vytváření tzv. pastí,
////kdy do nich uložíte výsledek operace a následně vypíšete na seriovém monitoru.
////Ve finálním programu by neměly být, slouží čistě pro účely ladění.
////  int help1 = 0;
////  int help2 = 0;
////  int help3 = 0;
////  int help4 = 0;
////Vypsání hodnot proměnných
//  //  Serial.print("stateB ");
//  //  Serial.println(stateB);
//  //  Serial.print("brightLED ");
//  //  Serial.println(brightLED);
//
////Testování dlouhého stisknutí tlačítka (1000 ms)
////Past na detekci dlouhého stisku tlačítka
////  if (help2 = M5.Btn.pressedFor(1000)) {
////    Serial.print("help2 ");
////    Serial.println(help2);
////Pokud se použije past, následující řádek se zakomentuje.
//  if (M5.Btn.pressedFor(1000)) {
//    if (stateB == 1) {
//      modeB = 1;
//      brightLED += 1;
//      if (brightLED > 254) brightLED = 254;
//    }
//    else {
//      modeB = 2;
//      brightLED -= 1;
//      if (brightLED < 1) brightLED = 1;
//    }
//  }
////Testování krátkéhho stisknutí tlačítka (30 ms)
////Past na detekci krátkého stisknutí tlačítka
////  else if (help1 = M5.Btn.pressedFor(30)) {
////    Serial.print("help1 ");
////    Serial.println(help1);
////Pokud se použije past, následující řádek se zakomentuje.
//  else if (M5.Btn.pressedFor(30)) {
//    if (stateB == 1) {
//      modeB = 3;
//    }
//    else {
//      modeB = 4;
//    }
//  }
//
////Pokud bylo tlačítko puštěno, vyhodnotí se a provede krátký
////stisk tlačítka
//  if (M5.Btn.wasReleased()) {
////Past na detekci, zda skutečně došlo k uvolnění tlačítka
////    Serial.println("**********");
//    stateB = !stateB;
//    switch (modeB) {
//      case 1:
//
//        break;
//      case 2:
//
//        break;
//      case 3:
//        brightLED = 255;
//        brightB = 255;
//        break;
//      case 4:
//        brightLED = 0;
//        brightB = 0;
//        break;
//    }
//  }
//
////Na konci se nastaví jas, rozsvítí LED a přečtou vstupy
//  M5.dis.setBrightness(brightLED);
//  M5.dis.drawpix(RGB_LED, 0xff0000);
//  M5.update();
////Určuje rychlost stmívání
//  delay(50);
//}



//***************************************************
//Zapnutí a vypnutí jedním tlačítkem
//***************************************************
/*Funkce pro práci s LED a tlačítkem jsou popsány v
  https://docs.m5stack.com/en/api/atom/system
  https://docs.m5stack.com/en/api/atom/button
  https://docs.m5stack.com/en/api/atom/led_display
*/
//#include "M5Atom.h"
//
//#define RGB_LED 0
//
//void setup() {
//  M5.begin(true, false, true);
//  delay(50);
//  //Na začátku problikne LED pro ověření, že funguje
//  M5.dis.drawpix(RGB_LED, 0x00FF00);
//  delay(50);
//  M5.dis.drawpix(RGB_LED, 0x000000);
//}
//
//void loop() {
//  static bool stateB = 0;
//  //Pokud bylo stisknuto tlačítko, změní se stav LED
//  if(M5.Btn.wasPressed()) {
//    stateB = !stateB;
//  }
//  if(stateB == 0) {
//    M5.dis.drawpix(RGB_LED, 0x000000);
//  }
//  else {
//    M5.dis.drawpix(RGB_LED, 0x0000ff);
//  }
//  M5.update();
//}

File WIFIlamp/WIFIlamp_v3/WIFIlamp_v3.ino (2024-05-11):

// Desku připojíte jako Deneyap Mini (možná i jiná deska)
// Aby se dala programovat, je třeba držet boot a resetovat čip
// Jak naprogramovat ESP32 S2F
// https://youtu.be/Ull2gCKb1Yw?feature=shared

// Projekt podle
// https://randomnerdtutorials.com/esp32-esp8266-web-server-physical-button/

//***************************************************
// Vytvořte soubor wifiConfig.h
// a vyplnte v něm následující údaje
// Device ID a Secret Key vygeneruje Arduino cloud

/* VYPLNTE NAZEV WIFI SITE A HESLO  */
// #define SECRET_SSID "SSID"
// #define SECRET_OPTIONAL_PASS "password"
//
/* Nastavení sítě */
// IPAddress local_IP(192, 168, 30, 30);
// IPAddress gateway(192, 168, 1, 1);
// IPAddress subnet(255, 255, 255, 0);
// //IPAddress primaryDNS(8, 8, 8, 8);   // optional
// //IPAddress secondaryDNS(8, 8, 4, 4); // optional
//***************************************************

//knihovny
#include "wifiConfig.h"
#include <WiFi.h>
#include <AsyncTCP.h>           // AsyncTCP by dvarrel, v. 1.1.4 - https://github.com/me-no-dev/AsyncTCP
#include <ESPAsyncWebServer.h>  // ESPAsyncWebServer by lacamera - https://github.com/me-no-dev/ESPAsyncWebServer

// parametry k připojení k síti
const char *ssid = SECRET_SSID;               // název sítě
const char *password = SECRET_OPTIONAL_PASS;  // heslo k síti

const char *PARAM_INPUT_1 = "state";

const int output = 1;     //nastevení pinu pro ovládání tranzitoru
const int buttonPin = 2;  //nastavení vstupního pinu tlačítka


int ledState = LOW;         //nastavení první hodnoty LED
int buttonState;            //definování vstupního pinu tlačítka jako dvouhodnotovou proměnnou
int lastButtonState = LOW;  //pomocná porměnná pro fungování

//doba stisku tlačítka pro zaregistrování stisku
unsigned long lastDebounceTime = 0;
unsigned long debounceDelay = 50;

AsyncWebServer server(80);  //zavedení serveru na port 80

//zde začíná část HTML programu pro webové rozhraní

const char index_html[] PROGMEM = R"rawliteral(
<!DOCTYPE HTML><html>
<head>
  <title>ESP Web Server</title>
  <meta name="viewport" content="width=device-width, initial-scale=1">
  <style>
    html {font-family: Arial; display: inline-block; text-align: center;}
    h2 {font-size: 3.0rem;}
    p {font-size: 3.0rem;}
    body {max-width: 600px; margin:0px auto; padding-bottom: 25px;}
    .switch {position: relative; display: inline-block; width: 120px; height: 68px} 
    .switch input {display: none}
    .slider {position: absolute; top: 0; left: 0; right: 0; bottom: 0; background-color: #ccc; border-radius: 34px}
    .slider:before {position: absolute; content: ""; height: 52px; width: 52px; left: 8px; bottom: 8px; background-color: #fff; -webkit-transition: .4s; transition: .4s; border-radius: 68px}
    input:checked+.slider {background-color: #2196F3}
    input:checked+.slider:before {-webkit-transform: translateX(52px); -ms-transform: translateX(52px); transform: translateX(52px)}
  </style>
</head>
<body>
  <h2>ESP Web Server</h2>
  %BUTTONPLACEHOLDER%
<script>function toggleCheckbox(element) {
  var xhr = new XMLHttpRequest();
  if(element.checked){ xhr.open("GET", "/update?state=1", true); }
  else { xhr.open("GET", "/update?state=0", true); }
  xhr.send();
}
setInterval(function ( ) {
  var xhttp = new XMLHttpRequest();
  xhttp.onreadystatechange = function() {
    if (this.readyState == 4 && this.status == 200) {
      var inputChecked;
      var outputStateM;
      if( this.responseText == 1){ 
        inputChecked = true;
        outputStateM = "On";
      }
      else { 
        inputChecked = false;
        outputStateM = "Off";
      }
      document.getElementById("output").checked = inputChecked;
      document.getElementById("outputState").innerHTML = outputStateM;
    }
  };
  xhttp.open("GET", "/state", true);
  xhttp.send();
}, 1000 ) ;
</script>
</body>
</html>
)rawliteral";

// Funkce pro nahrazení placeholderu v HTML kódu - změní vzhled checkboxu
// Replaces placeholder with button section in your web page
String processor(const String &var) {
  //Serial.println(var);
  if (var == "BUTTONPLACEHOLDER") {
    String buttons = "";
    String outputStateValue = outputState();
    buttons += "<h4>Output - GPIO 2 - State <span id=\"outputState\"></span></h4><label class=\"switch\"><input type=\"checkbox\" onchange=\"toggleCheckbox(this)\" id=\"output\" " + outputStateValue + "><span class=\"slider\"></span></label>";
    return buttons;
  }
  return String();
}

//Nastavení stavu checkboxu
String outputState() {
  if (digitalRead(output)) {
    return "checked";
  } else {
    return "";
  }
  return "";
}

void setup() {
  Serial.begin(115200);

  pinMode(output, OUTPUT);    //nastavení pinu pro výstup jako výstup
  digitalWrite(output, LOW);  //naství hodnotu 0 na výstupu pro případ výpadek elektriky
  pinMode(buttonPin, INPUT_PULLUP);  //nastavení pinu tlačítka jako vstup

  byte countConnect = 0;
  Serial.println("Connecting to WiFi");
  
  //Nastavení pevné IP adresy
  //if (!WiFi.config(local_IP, gateway, subnet, primaryDNS, secondaryDNS))
  if (!WiFi.config(local_IP, gateway, subnet))
  {
    Serial.println("STA Failed to configure");
  }
  
  WiFi.begin(ssid, password);  //zahájení wifi komunikace
  while (WiFi.status() != WL_CONNECTED && countConnect < 10)
  {
    delay(500);
    Serial.println(".");
    countConnect++;
  }

  Serial.println(WiFi.localIP()); //vypsání IP adresy

// Nastavení serveru
  server.on("/", HTTP_GET, [](AsyncWebServerRequest *request) {
    request->send_P(200, "text/html", index_html, processor);
  });

// Nastavení serveru pro ovládání LED přes web
  server.on("/update", HTTP_GET, [](AsyncWebServerRequest *request) {
    String inputMessage;
    String inputParam;
    if (request->hasParam(PARAM_INPUT_1)) {
      inputMessage = request->getParam(PARAM_INPUT_1)->value();
      inputParam = PARAM_INPUT_1;
      digitalWrite(output, inputMessage.toInt());
      ledState = !ledState;
    } else {
      inputMessage = "No message sent";
      inputParam = "none";
    }
    Serial.println(inputMessage);
    request->send(200, "text/plain", "OK");
  });

// Nastavení serveru pro získání stavu LED
  server.on("/state", HTTP_GET, [](AsyncWebServerRequest *request) {
    request->send(200, "text/plain", String(digitalRead(output)).c_str());
  });

  // Spuštění serveru
  server.begin();
}

void loop() {

  int reading = digitalRead(buttonPin);

  if (reading != lastButtonState) {

    lastDebounceTime = millis();
  }

  if ((millis() - lastDebounceTime) > debounceDelay) {


    if (reading != buttonState) {
      buttonState = reading;

      if (buttonState == HIGH) {
        ledState = !ledState;
      }
    }
  }

  digitalWrite(output, ledState);

  lastButtonState = reading;
}

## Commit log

2023-01-03 Přidáno schéma pro LEDlamp
    [LEDlamp.kicad_sch]
2023-01-04 Přidány fotky LED lampičky
2023-01-07 Update README.md
    Readme.md - dopsané Problémy a řešení pro LEDlamp
2023-02-04 Velká záloha: roztříděny programy, částečně doplněno Readme, fotky...
    [HEX light WS2812.kicad_pcb, HEX light WS2812.kicad_sch]
2023-02-09 Schéma RGB lamp
    [Zapojeni RGB lampicky.kicad_pcb, Zapojeni RGB lampicky.kicad_sch]
2023-02-13 Doplněn Readme a fotka RGB lampičky
    [Zapojeni RGB lampicky.kicad_sch]
2024-04-19 Plně funkční přes Arduino cloud, zpoždění přes delay
